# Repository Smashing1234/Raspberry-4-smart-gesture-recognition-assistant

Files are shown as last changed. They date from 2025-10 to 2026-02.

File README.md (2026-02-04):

  
# Raspberry 4 smart gesture recognition assistant
The main motivation behind the project is to help people with hearing impairments gain easy access to smart home technologies. Since voice assistants are useless for them, and wearable devices like hearing-impaired gloves are not always convenient, the Smart Gesture Station was created. It is a prototype based on Raspberry Pi that uses a camera to recognize intuitive gestures, allowing users to control their homes and send emergency signals quickly, without the need for voice.

## Purpose and description
Now I will explain step by step how I was able to implement this project. Before I start, I'll tell you what the point of all this is. I did this project to solve one of the social problems of the deaf and people with disabilities, I think it can give rise to something bigger and better.  My project is a kind of "voice assistant" Siri, Alice, and so on. Based on them, I made this project. My project can recognize gestures such as fist and the "OK" gesture, as well as recognize claps, while performing various tasks. The first task is to turn on and off a relay with an LED that simulates light, with two claps or clenching and unclenching of a fist.  Another task is to notify relatives to whom emergency messages are sent with an "OK" gesture.

## Project objectives:
- Develop an algorithm for recognizing intuitive gestures (fist, "OK") and sound patterns (clap) based on computer vision and audio analysis libraries.
- Implement a wireless device control module using the MQTT protocol and an emergency notification system using the Telegram Bot API.
- Design, build, and programmatically configure a hardware prototype based on Raspberry Pi with a camera, microphone, and feedback modules (LCD display, sensors).
- Test the prototype's functionality by evaluating its recognition accuracy, response latency, and overall practical applicability.
  
## Performance

https://github.com/user-attachments/assets/2430dc74-bb1f-4c9f-a8ee-8e46b0dc5894

# Step-by-step implementation plan

## Part 1. Necessary resources
For this project, we will need:
Raspberry 4 or 5, Power supply, SD card from 16 GB, the more the better, a camera that works on USB, a microphone is also USB, but I have a microphone built into the camera, a wire with a miniHDMI connector, a monitor, a keyboard, a mouse. For the second part of the project with the connection of the relay via the MQTT protocol, you will need:
ESP8266, a power supply for it, see the relay in the photo, a breadboard, but you can also use it without it, wires, an LED, a resistor. You definitely need a PC and an Internet connection.

IMG_3336 (2)

## Part 2. The first introduction to Raspberry
The very first thing you need to do is download the system image 2025-05-06-raspios-bullseye-arm64.img.xz (you can install its archive by going to the main [window](https://github.com/Smashing1234/Raspberry-4-smart-gesture-recognition-assistant/blob/main/2025-05-06-raspios-bullseye-arm64.img.xz.torrent ) and install it on the SD using the Raspberry Pi Imager program. To do this, run the Raspberry Pi Imager program, select which device you will install on, and then select with another button that you want to use your img image. And install it



## Part 3. Installing libraries for hand recognition. OpenCV. Mediapipe. Hand recognition
The next step is to download the libraries for gesture recognition and camera control, you can see it [here](https://github.com/Smashing1234/Raspberry-4-smart-gesture-recognition-assistant/blob/main/Hand%20recognition.py)

## Part 4. Installing Tasmota. MQTT. Fist gesture. ESP8266. Turning lights on and off with a fist gesture
In the next step, we will be able to control the ESP8266 using Raspberry 4, you can see it [here](https://github.com/Smashing1234/Raspberry-4-smart-gesture-recognition-assistant/blob/main/MQTT%20connection.py) and you can download the Tasmota version [here](https://github.com/Smashing1234/Raspberry-4-smart-gesture-recognition-assistant/blob/main/tasmota.bin)



To download firmware 13.04.0, you need to download Tasmotizer and select your BIN file in it.

## Part 5. Pyaudio. microphone. Claps recognition
In this step, I've figured out how to recognize claps using a microphone, you can see it [here](https://github.com/Smashing1234/Raspberry-4-smart-gesture-recognition-assistant/blob/main/Clap%20recognition.py)

## Part 6. Sending notifications to Telegram. The "OK" gesture. Fist gesture. API Bot Telegram
Here I was able to initialize the OK gesture, after which a telegram notification is sent. I also connected it with a 4-part code, you can see it [here](https://github.com/Smashing1234/Raspberry-4-smart-gesture-recognition-assistant/blob/main/Sending%20notifications%20in%20telegram.py)

## Part 7. Usage: ESP8266, Relay, MQTT, Tasmota, LED, Resistor, Clap recognition, gesture recognition
Here I combined all the parts into one, using a relay and an LED and a resistor, you can see it [here](https://github.com/Smashing1234/Raspberry-4-smart-gesture-recognition-assistant/blob/main/Connecting%20Relay.py)



# Key changes/improvements for 2026:

## Part 8.1. Upgrade to Sonoff R4
I changed the esp8266 to an esp32. The esp32 and the relay were built into the sonoff R4 module, so I only had to flash the esp32 and install Tasmota.

tasmota 1 1 jpg

## Part 8.2. Creating a case
In order to make my project look like a regular mini-station, I had to create and print a 3D model of the [case](https://github.com/Smashing1234/Raspberry-4-smart-gesture-recognition-assistant/commit/7dd63af01491b17ffcb7aef9a9fa4ca3d35caa46). Keep in mind that I already have active cooling for the case, which significantly changes the original dimensions.

весь корпус

## Part 8.3. Display and temperature sensor
I also added the lcd1602 display (using the i2c protocol) and the DHT11 module to the project. Information about [lcd1602](https://peppe8o.com/1602-lcd-raspberry-pi-display/) and information about [dht11](https://www.raspberrypi-5.com/how-to-connect/how-to-connect-dht11-to-raspberry-pi/)



## Part 8.4. Mini conclusion
In general, the changes were more visual. I switched to a ready-made version in the form of a sonoff R4, and I also used a screen to display the program's status, including temperature and humidity data.

## Results
To test the concept, a functional prototype of the system was assembled and implemented in software. In practice, it was possible to verify how the theoretical principles — lightweight geometric gesture analysis instead of ML, local data processing, and a modular architecture — are implemented in a real device. 

- Results of the total delay of the fist recognition (from recognition to changing the relay state):

График кулаков в2

- Results of the total double-tap recognition delay (from recognition to change of the retransmission status):

График хлопков в2

- Program completion percentage results:

Проц выпол в2

## Conclusion
A working prototype of an assistive system has been created. This prototype proves the possibility of recognizing gestures using a camera and lightweight algorithms on a Raspberry Pi. It functions as a prototype of a local platform for controlling devices over Wi-Fi and sending emergency alerts, offering a practical prototype of a solution for contactless interaction with a smart home. Recognition accuracy: 80% (gestures), 65% (claps), execution delays vary from 1.5 to 3 seconds depending on the action

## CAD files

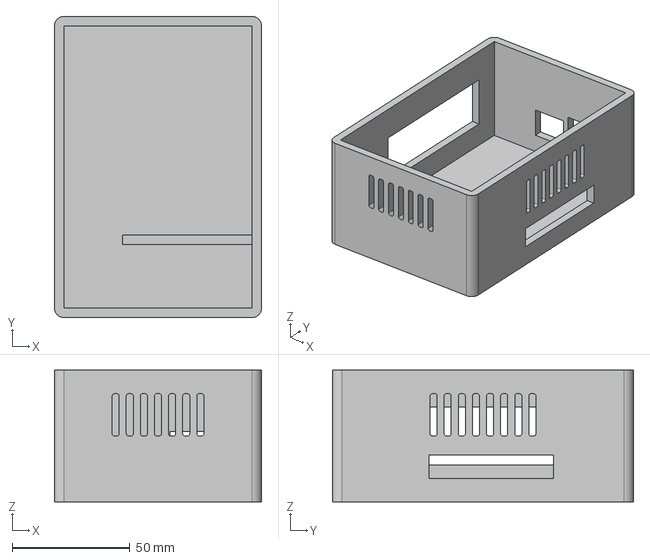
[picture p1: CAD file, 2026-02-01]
корпус v5.1.stp
88.0 x 128.0 x 56.0 mm

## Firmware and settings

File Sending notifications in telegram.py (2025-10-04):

# Before you start, create a bot in telegram, get a unique API from it, and also find out from those who will need to send messages their telegram ID.
# The command to install the library on Raspberry
pip3 install python-telegram-bot

import cv2
import mediapipe as mp
import time
import requests
import paho.mqtt.client as mqtt

# ===== Settings =====
TELEGRAM_BOT_TOKEN = "" # Bot API token in Telegram
TELEGRAM_CHAT_ID = "" # User ID

# ===== MQTT Settings =====
MQTT_BROKER = ""  # Raspberry Pi IP
MQTT_PORT = 1883
MQTT_TOPIC = "cmnd/tasmota_DEE65D/POWER"
MQTT_USER = "DVES_USER"
MQTT_PASS = "147"

# ===== Variables =====
last_call_time = 0
call_cooldown = 300  # 5 minutes between calls
hold_time_needed = 2  # 2 seconds holding time
max_distance = 24  # 24 pixels between fingers

# ===== Initialization =====
mp_hands = mp.solutions.hands
hands = mp_hands.Hands(max_num_hands=1, min_detection_confidence=0.7)
cap = cv2.VideoCapture(0)

# ===== MQTT Client =====
mqtt_client = mqtt.Client()

def connect_mqtt():
    """Connect to MQTT broker"""
    try:
        mqtt_client.username_pw_set(MQTT_USER, MQTT_PASS)
        mqtt_client.connect(MQTT_BROKER, MQTT_PORT, 60)
        mqtt_client.loop_start()
        print("Connected to MQTT broker")
        return True
    except Exception as e:
        print(f"MQTT connection error: {e}")
        return False

def control_light(state):
    """Control light on ESP8266"""
    command = "ON" if state else "OFF"
    try:
        mqtt_client.publish(MQTT_TOPIC, command)
        print(f"Command sent: {command}")
    except Exception as e:
        print(f"Command sending error: {e}")

# ===== Message sending function =====
def send_emergency():
    global last_call_time
    current_time = time.time()

    if current_time - last_call_time < call_cooldown:
        return False

    try:
        url = f"https://api.telegram.org/bot{TELEGRAM_BOT_TOKEN}/sendMessage"
        data = {
            'chat_id': TELEGRAM_CHAT_ID,
            'text': "🚨 EMERGENCY CALL 🚨\n\nUser needs help!"
        }
        response = requests.post(url, data=data, timeout=5)
        last_call_time = current_time
        return response.status_code == 200
    except:
        return False

def is_finger_extended(pip, dip, tip):
    """Check if finger is extended (tip above joints)"""
    return tip[1] < pip[1] and tip[1] < dip[1]

def detect_gesture(landmarks, h, w):
    """Detect fist or palm"""
    lm = [(int(p.x * w), int(p.y * h)) for p in landmarks.landmark]

    fingers = []
    # Thumb
    fingers.append(1 if lm[4][0] > lm[3][0] else 0)
    # Other 4 fingers
    for tip in [8, 12, 16, 20]:
        fingers.append(1 if lm[tip][1] < lm[tip - 2][1] else 0)

    if sum(fingers) == 0:
        return "fist"
    elif sum(fingers) == 5:
        return "palm"
    else:
        return "other"

# ===== Connect MQTT =====
if not connect_mqtt():
    print("Working without MQTT (simulation only)")

# ===== Main loop =====
gesture_start_time = 0
gesture_detected = False
fist_start_time = 0
fist_detected = False
lights_on = False
light_cooldown = 2  # delay between light toggles
last_light_time = 0

print("System started!")
print("Gestures:")
print("  - Fist: turn light on/off")
print("  - OK (2 sec): emergency call")

while True:
    success, frame = cap.read()
    if not success:
        continue

    frame = cv2.flip(frame, 1)
    h, w, _ = frame.shape
    rgb = cv2.cvtColor(frame, cv2.COLOR_BGR2RGB)
    results = hands.process(rgb)

    current_ok_gesture = False
    current_fist_gesture = False
    current_gesture = "none"

    if results.multi_hand_landmarks:
        for hand in results.multi_hand_landmarks:
            # Get finger points
            landmarks = []
            for point in hand.landmark:
                x = int(point.x * w)
                y = int(point.y * h)
                landmarks.append((x, y))

            # All finger points
            thumb_tip = landmarks[4]
            index_tip = landmarks[8]
            middle_tip = landmarks[12]
            ring_tip = landmarks[16]
            pinky_tip = landmarks[20]

            # Finger joints for extension check
            index_pip = landmarks[6]
            index_dip = landmarks[7]
            middle_pip = landmarks[10]
            middle_dip = landmarks[11]
            ring_pip = landmarks[14]
            ring_dip = landmarks[15]
            pinky_pip = landmarks[18]
            pinky_dip = landmarks[19]

            # Calculate distance between thumb and index finger
            dx = thumb_tip[0] - index_tip[0]
            dy = thumb_tip[1] - index_tip[1]
            distance = (dx * dx + dy * dy) ** 0.5

            # Check if other fingers are extended
            middle_extended = is_finger_extended(middle_pip, middle_dip, middle_tip)
            ring_extended = is_finger_extended(ring_pip, ring_dip, ring_tip)
            pinky_extended = is_finger_extended(pinky_pip, pinky_dip, pinky_tip)

            # OK gesture: thumb and index connected, other fingers extended
            if (distance < max_distance and
                    middle_extended and
                    ring_extended and
                    pinky_extended):
                current_ok_gesture = True

            # Detect gesture using new function
            current_gesture = detect_gesture(hand, h, w)
            if current_gesture == "fist":
                current_fist_gesture = True

    # OK gesture processing
    current_time = time.time()

    if current_ok_gesture:
        if not gesture_detected:
            gesture_detected = True
            gesture_start_time = current_time
            print("OK gesture detected...")

        # Calculate remaining time
        hold_time = current_time - gesture_start_time
        time_left = hold_time_needed - hold_time

        if time_left > 0:
            # Show countdown
            cv2.putText(frame, f"EMERGENCY CALL: {time_left:.1f}s", (w // 2 - 150, 70),
                        cv2.FONT_HERSHEY_SIMPLEX, 0.7, (0, 0, 255), 2)
        else:
            # Send message
            if send_emergency():
                cv2.putText(frame, "CALL SENT!", (w // 2 - 70, 100),
                            cv2.FONT_HERSHEY_SIMPLEX, 0.7, (0, 255, 0), 2)
                print("Emergency call sent!")
            else:
                cv2.putText(frame, "ERROR!", (w // 2 - 40, 100),
                            cv2.FONT_HERSHEY_SIMPLEX, 0.7, (0, 0, 255), 2)

            gesture_detected = False
            time.sleep(2)
    else:
        gesture_detected = False

    # Fist gesture processing (light control)
    if current_fist_gesture:
        if not fist_detected:
            fist_detected = True
            fist_start_time = current_time
            print("Fist detected!")

            # Toggle light only if enough time passed since last toggle
            if current_time - last_light_time > light_cooldown:
                lights_on = not lights_on
                last_light_time = current_time
                control_light(lights_on)
                print(f"Light toggled: {'ON' if lights_on else 'OFF'}")

    else:
        fist_detected = False

    # Display information (top panel)
    cv2.rectangle(frame, (0, 0), (w, 30), (0, 0, 0), -1)
    status = "READY" if not gesture_detected else "HOLDING OK"
    cv2.putText(frame, f"STATUS: {status}", (10, 20),
                cv2.FONT_HERSHEY_SIMPLEX, 0.5, (255, 255, 255), 1)

    cv2.putText(frame, f"LIGHT: {'ON' if lights_on else 'OFF'}", (w - 120, 20),
                cv2.FONT_HERSHEY_SIMPLEX, 0.5, (0, 255, 0) if lights_on else (0, 0, 255), 1)

    # Display current gesture
    cv2.putText(frame, f"CURRENT GESTURE: {current_gesture.upper()}", (10, h - 20),
                cv2.FONT_HERSHEY_SIMPLEX, 0.5, (200, 200, 200), 1)

    # Instruction at bottom
    cv2.putText(frame, "Press 'Q' to quit", (w - 150, h - 20),
                cv2.FONT_HERSHEY_SIMPLEX, 0.5, (255, 255, 255), 1)

    cv2.imshow("Gesture Control System", frame)

    if cv2.waitKey(5) & 0xFF == ord('q'):
        break

cap.release()
cv2.destroyAllWindows()
mqtt_client.loop_stop()
mqtt_client.disconnect()
print("System stopped")

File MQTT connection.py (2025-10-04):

#Before you start installing libraries and coding, install the firmware 13.04.0 for ESP8266 listed on the homepage, I installed it via Tasmotizer using my (bin) image
# On Raspberry Pi 4:
# Complete installation
sudo apt remove --purge mosquitto mosquitto-client  # If installed incorrectly
sudo rm -rf /etc/mosquitto/ /var/log/mosquitto/  # If installed incorrectly
sudo apt update
sudo apt install mosquitto mosquitto-clients
sudo systemctl enable mosquitto  # Auto-start on Raspberry Pi boot
sudo systemctl start mosquitto

sudo nano /etc/mosquitto/mosquitto.conf
# Add:

listener 1883
allow_anonymous true

sudo systemctl restart mosquitto

# Verify MQTT is working:
# Terminal 1 - subscription (listen for messages)
mosquitto_sub -h localhost -t "test" -v

# Terminal 2 - publication (send message)
mosquitto_pub -h localhost -t "test" -m "hello"

# Subscribe to Tasmota topics:
mosquitto_sub -h localhost -t "tele/#" -v

# Find IP for ESP on Raspberry Pi:
hostname -I

# On ESP:
# Download Tasmotizer, install firmware
# Then connect to wifi and MQTT by entering the Raspberry Pi IP we found earlier

# Configuration --> Module --> GPIO2 LED1

# After loading code on Raspberry Pi 4, install paho-mqtt library:
pip3 install paho-mqtt

# Main code:
import cv2
import mediapipe as mp
import time
import paho.mqtt.client as mqtt
import json

# ===== MQTT Settings =====
MQTT_BROKER = ""  # Your Raspberry Pi IP - set it yourself!!!!!
MQTT_PORT = 1883
MQTT_TOPIC = "cmnd/tasmota_DEE65D/POWER"
MQTT_USER = "DVES_USER"  # if exists
MQTT_PASS = "147"  # if exists

# ===== MQTT Client =====
mqtt_client = mqtt.Client()

# If authentication required:
# mqtt_client.username_pw_set(MQTT_USER, MQTT_PASS)

def connect_mqtt():
    """Connect to MQTT broker"""
    try:
        mqtt_client.connect(MQTT_BROKER, MQTT_PORT, 60)
        mqtt_client.loop_start()
        print("Connected to MQTT broker")
        return True
    except Exception as e:
        print(f"MQTT connection error: {e}")
        return False

def control_light(state):
    """Control light on ESP8266"""
    command = "ON" if state else "OFF"
    try:
        mqtt_client.publish(MQTT_TOPIC, command)
        print(f"Command sent: {command}")
    except Exception as e:
        print(f"Command sending error: {e}")

# ===== System State =====
class SystemState:
    pass

state = SystemState()
state.lights_on = False
state.last_time = 0
state.cooldown = 2  # delay between gestures

# ===== MediaPipe =====
mp_hands = mp.solutions.hands
mp_drawing = mp.solutions.drawing_utils
hands = mp_hands.Hands(max_num_hands=1, min_detection_confidence=0.7)

# ===== Connect MQTT =====
if not connect_mqtt():
    print("Working without MQTT (simulation only)")

cap = cv2.VideoCapture(0)

def detect_gesture(landmarks, h, w):
    """Detect fist or palm"""
    lm = [(int(p.x * w), int(p.y * h)) for p in landmarks.landmark]

    fingers = []
    # Thumb
    fingers.append(1 if lm[4][0] > lm[3][0] else 0)
    # Other 4 fingers
    for tip in [8, 12, 16, 20]:
        fingers.append(1 if lm[tip][1] < lm[tip - 2][1] else 0)

    if sum(fingers) == 0:
        return "fist"
    elif sum(fingers) == 5:
        return "palm"
    else:
        return "other"

print("Starting light control system...")
print("Gestures: Fist - toggle light, Q - exit")

while True:
    ret, frame = cap.read()
    if not ret:
        break

    frame = cv2.flip(frame, 1)  # mirror
    h, w, _ = frame.shape
    rgb = cv2.cvtColor(frame, cv2.COLOR_BGR2RGB)
    results = hands.process(rgb)

    gesture = "none"
    if results.multi_hand_landmarks:
        for hand_landmarks in results.multi_hand_landmarks:
            mp_drawing.draw_landmarks(frame, hand_landmarks, mp_hands.HAND_CONNECTIONS)
            gesture = detect_gesture(hand_landmarks, h, w)

    # toggle light with fist
    if gesture == "fist" and time.time() - state.last_time > state.cooldown:
        state.lights_on = not state.lights_on
        state.last_time = time.time()

        # Control real light on ESP8266
        control_light(state.lights_on)

        print(f"Light toggled: {'ON' if state.lights_on else 'OFF'}")

    # ===== On-screen text =====
    status_text = f"Light: {'ON' if state.lights_on else 'OFF'}"
    gesture_text = f"Gesture: {gesture}"

    cv2.putText(frame, status_text, (50, 50),
                cv2.FONT_HERSHEY_SIMPLEX, 1, (0, 255, 0) if state.lights_on else (0, 0, 255), 2)

    cv2.putText(frame, gesture_text, (50, 100),
                cv2.FONT_HERSHEY_SIMPLEX, 0.7, (255, 255, 255), 2)

    cv2.putText(frame, "Q - quit", (50, h - 30),
                cv2.FONT_HERSHEY_SIMPLEX, 0.7, (255, 255, 255), 2)

    cv2.imshow("Light Control by Gesture", frame)

    if cv2.waitKey(5) & 0xFF == ord("q"):
        break

# ===== Cleanup =====
cap.release()
cv2.destroyAllWindows()
mqtt_client.loop_stop()
mqtt_client.disconnect()
print("System stopped")


# If connection fails, reconnect and reboot ESP

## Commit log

2025-10-04 Update Install package.py
    This file contains the necessary libraries for gesture recognition and camera initialization on Raspberry 4.
2025-10-04 Add files via upload
    This firmware version for Raspberry4 is needed for the correct operation of the system.
2025-10-04 Add files via upload
    With this, you can test the operation of the MQTT protocol. To do this, you will need an ESP8266, a power supply to it. In this file you will find which libraries are needed, as well as how to use th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
2025-10-04 Add files via upload
    This file contains the final code. Also for this step, you will need a relay, an LED, a 220 ohm resistor, connection wires, and an ESP8266 with a power supply.
2025-10-11 Update Connecting Relay.py
